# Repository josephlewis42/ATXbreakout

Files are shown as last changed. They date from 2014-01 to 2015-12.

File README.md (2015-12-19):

ATX Breakout Board
==================

An ATX power supply breakout. Eagle files are included.

Features
--------

* Small footprint 1.5" x 3" (38 x 76mm) greatly beats Dangerous Prototype's
* Large traces so you can pull power without burning traces (unlike SpartFun's)
* Large, sturdy mounting-holes with edge clearance means no more torn boards
* Optional power indicator LED
* Optional resettable fuses (can be bypassed with a jumper)
* Supports posts and break-away headers for powering your projects--good for both benchtop and embedded use
* On/Off switch
* Supports both 20 and 24 pin ATX 

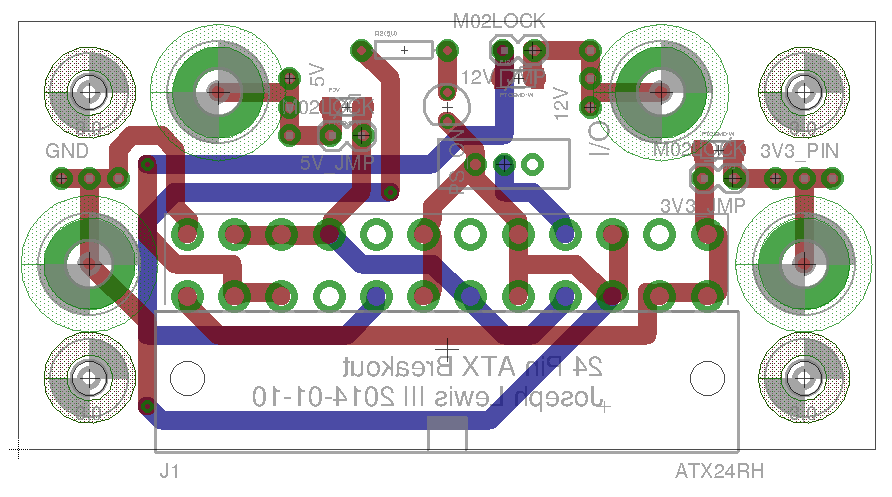
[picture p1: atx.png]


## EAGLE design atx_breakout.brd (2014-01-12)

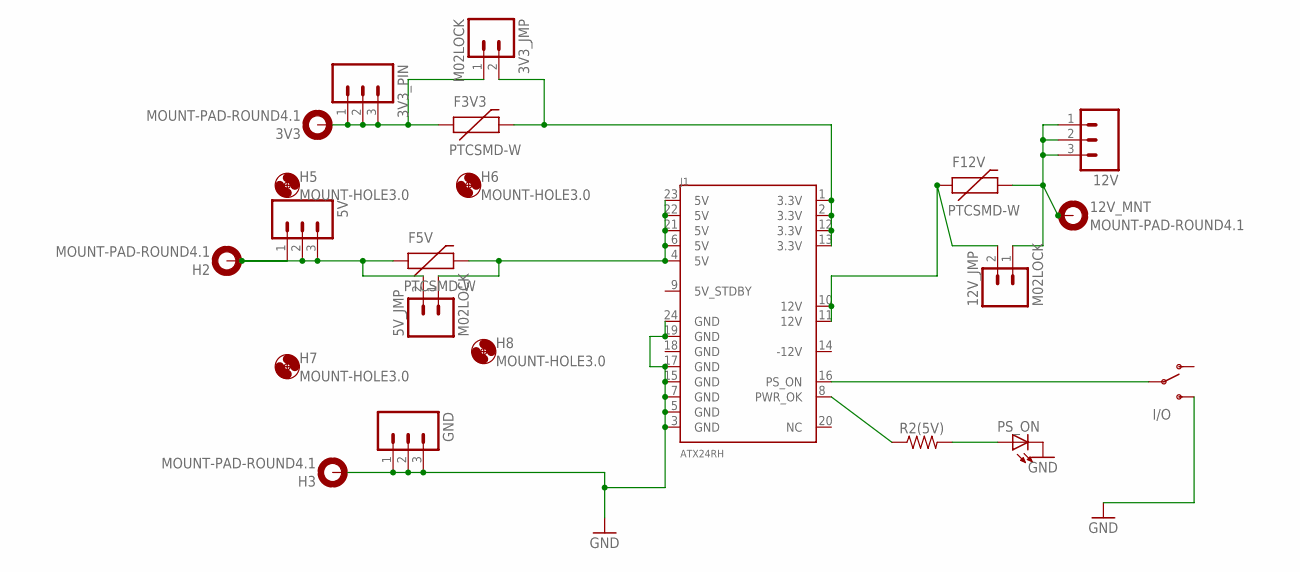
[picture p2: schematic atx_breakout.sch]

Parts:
3V3, 12V_MNT: MOUNT-PAD-ROUND4.1; 4,1-PAD
3V3_JMP, 5V_JMP, 12V_JMP: M02LOCK; 1X02_LOCK
3V3_PIN, 5V, 12V: M031X03_NO_SILK; 1X03_NO_SILK
F3V3, F5V, F12V: PTCSMD-W; PTC-1206-WIDE
GND: M031X03_NO_SILK; 1X03_NO_SILK
H2, H3: MOUNT-PAD-ROUND4.1; 4,1-PAD
H5, H6, H7, H8: MOUNT-HOLE3.0; 3,0
I/O: SWITCH-SPDTPTH; SWITCH-SPDT
J1: ATX24RH; ATX24_RIGHT_ANGLE
PS_ON: LED-3MM-NO_SILK; LED3MM-NS
R2(5V): RESISTORAXIAL-0.3; AXIAL-0.3

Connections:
5VFUSE: 5V.1, 5V.2, 5V.3, 5V_JMP.2, F5V.1, H2.B4,1
GND: GND.1, GND.2, GND.3, H3.B4,1, I/O.3 (S), J1.3 (GND), J1.5 (GND), J1.7 (GND), J1.15 (GND), J1.17 (GND), J1.19 (GND), J1.24 (GND), PS_ON.K (C)
unnamed: J1.8 (PWR_OK), R2(5V).P$1 (1)
unnamed: 3V3_JMP.2, F3V3.2, J1.1 (3.3V), J1.2 (3.3V), J1.12 (3.3V), J1.13 (3.3V)
unnamed: 12V_JMP.2, F12V.1, J1.10 (12V), J1.11 (12V)
unnamed: 3V3.B4,1, 3V3_JMP.1, 3V3_PIN.1, 3V3_PIN.2, 3V3_PIN.3, F3V3.1
unnamed: 5V_JMP.1, F5V.2, J1.4 (5V), J1.6 (5V), J1.21 (5V), J1.22 (5V), J1.23 (5V)
unnamed: 12V.1, 12V.2, 12V.3, 12V_JMP.1, 12V_MNT.B4,1, F12V.2
unnamed: PS_ON.A, R2(5V).P$2 (2)
unnamed: I/O.2, J1.16 (PS_ON)

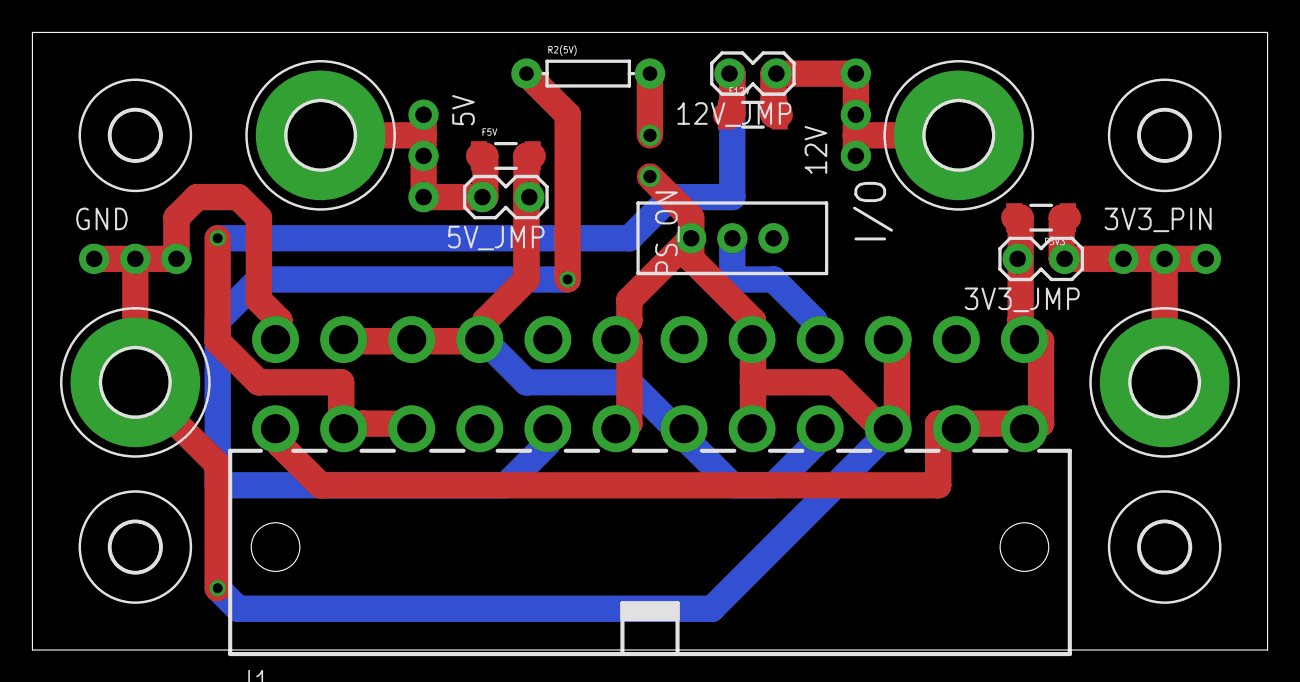
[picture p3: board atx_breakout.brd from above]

Board: 2 copper layers, 76.2 x 38.1 mm, 22 parts (0 on the bottom side), 10 nets.

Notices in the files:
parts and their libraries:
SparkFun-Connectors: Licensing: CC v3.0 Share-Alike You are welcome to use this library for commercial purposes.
